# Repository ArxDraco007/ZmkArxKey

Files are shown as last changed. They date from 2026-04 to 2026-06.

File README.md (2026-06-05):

# ArxKey - A Custom Split Keyboard

## Building a custom wireless split mechanical keyboard from scratch.

## Why did I make this project?
  There are a lot of ill effects of using a non-ergonomic keyboard. Some basic effects happen, such as ulnar deviation (bending wrists outward), forearm pronation (palms facing down), and unnatural extension. It might also get very serious if you have Carpal Tunnel Syndrome (CTS): The median nerve in the wrist is compressed, often due to swollen tendons. It leads to numbness, tingling, and weakened grip strength. As the times change, you will require a keyboard as it becomes an integral part of your everyday life. It is best to have an ergonomic (furniture or equipment that makes it comfortable and effective for people who use it) keyboard, to make sure you enjoy your work.
You can also type very fast. It is also a very fun project to make, and it is also very cool to have your own custom keyboard (split one too).
### PICTURES!!!
The easy part -

1775320786451-4x2p1t

The not-so-easy part - 

1775912615627-d0wt4m

fusio' - 
left

## Assembly instructions - 
1. Heat-press the brass inserts into the case and glue the magnets into place.
2. Screw the stabilizers into the PCB and mount the sliding switch to the case.
3. Solder the diodes, Hall sensors, and header pins to the Seeeduino and PCB.
4. Connect the battery wires to the BAT pins and the sliding power switch.
5. Tuck the battery into its cavity and screw the PCB into the case.
6. Click switches into the plate, screw the plate to the case, and add keycaps.
7. Flash your ZMK firmware to the Seeeduino.
8. Repeat for the second half, pair them, and test your work.
   
## How to use it?
1. Power on both halves, the keyboard will show as ArxSplit in the PC/Phone's Bluetooth settings.
2. The right and left layers are in the general QWERTY layout.
3. Plug the USB-C port into your PC or a charger. The XIAO powers on immediately and also charges the LiPo battery connected to the BAT/VBAT pads.
4. Flashing Firmware - Push the ZMK Files/ directory to a GitHub repo.
5. It will build two .uf2 files, my_keyboard_left and my_keyboard_right.
6. Double-tap the Reset button on the XIAO — it enters bootloader mode and mounts as a USB drive called XIAO-SENSE or NRF52BOOT. Drag and drop the .uf2 file onto that drive. It flashes automatically and reboots.

## Zine!

zine_page-0001

| Name | Purpose | Quantity | Total Cost (USD) | Link | Distributor |
| :--- | :--- | :---: | :---: | :--- | :--- |
| **Hotswap Socket** | Fittings for the Cherry MX | 50 | 6.00 | [https://stackskb.com/store/gateron-hotswap-sockets/](https://stackskb.com/store/gateron-hotswap-sockets/) | Stackskb |
| **Seeed XIAO nRF52840** | Must be the nRF52840 version for Bluetooth | 2 | 32.00 | [https://makerbazar.in/products/seeed-studio-xiao-esp32s3-2-4ghz-wifi-ble-5-0](https://www.mouser.in/ProductDetail/Seeed-Studio/102010448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) | MakerBazar  |
| **LiPo Battery (3.7V)** | Battery for powering wireless. | 2 | 6.00 | [https://www.electropi.in/3.7v-300mah-lipo-battery-model-401230-india](https://www.electropi.in/3.7v-300mah-lipo-battery-model-401230-india) | Electropi |
| **Diodes (1N4148W)** | Diodes for core functionality. | 100 | 1.50 | [https://robu.in/product/1n4148w-slkor-75v-1v-4ns-150ma-sod-123-switching-diodes-rohs](https://robu.in/product/1n4148w-slkor-75v-1v-4ns-150ma-sod-123-switching-diodes-rohs) | Robu |
| **Cherry MX Switches** | Cherry MX switches are the industry standard for mechanical keyboards | 45 | 18.75 | [https://meckeys.com/shop/accessories/keyboard-accessories/key-switches/cherry-mx-rgb-switch/](https://meckeys.com/shop/accessories/keyboard-accessories/key-switches/cherry-mx-rgb-switch/) | Meckeys |
| **Resistors** | resistors for core functionality | 1 | 2.00 | [https://robu.in/product/1k-ohm-1-4w-0805-surface-mount-chip-resistor-pack-of-10](https://robu.in/product/1k-ohm-1-4w-0805-surface-mount-chip-resistor-pack-of-10) | Robu |
| **Custom PCB (JLCPCB)** | $2 for boards + ~$8 global shipping | 1 | 10.00 | [https://jlcpcb.com/](https://jlcpcb.com/) | JLCPCB | 
| **TOTAL** | | | **76.25** | | |

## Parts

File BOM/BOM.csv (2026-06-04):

Name | Purpose | Quantity | Total Cost (USD) | Link | Distributor
Hotswap Socket | Fittings for the Cherry MX | 50 | 6.00 | https://stackskb.com/store/gateron-hotswap-sockets/ | Stackskb
LiPo Battery (3.7V) | Look for "301230" or "401230" sizes (100-150mAh). | 2 | 6.00 | https://www.electropi.in/3.7v-300mah-lipo-battery-model-401230-india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 | Electropi
Diodes (1N4148W) | SOD-123 size (as per your KiCad layout). | 100 | 1.50 | https://robu.in/product/1n4148w-slkor-75v-1v-4ns-150ma-sod-123-switching-diodes-rohs | Robu
Seeed XIAO nRF52840 | Must be the nRF52840 version for Bluetooth. | 2 | 32.00 | https://makerbazar.in/products/seeed-studio-xiao-esp32s3-2-4ghz-wifi-ble-5-0?variant=48251063075056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 | MakerBazar
Resistors | 0805 resistors. | 1 | 2.00 | https://robu.in/product/1k-ohm-1-4w-0805-surface-mount-chip-resistor-pack-of-10 | Robu
Custom PCB (JLCPCB) | $2 for the boards + ~$8 for global shipping. | 1 | 10.00 | https://jlcpcb.com/ | JLCPCB
Cherry MX Switches | The keys. | 45 | 18.75 | https://meckeys.com/shop/accessories/keyboard-accessories/key-switches/cherry-mx-rgb-switch/ | mckeys
Total Cost |  |  | $76.25

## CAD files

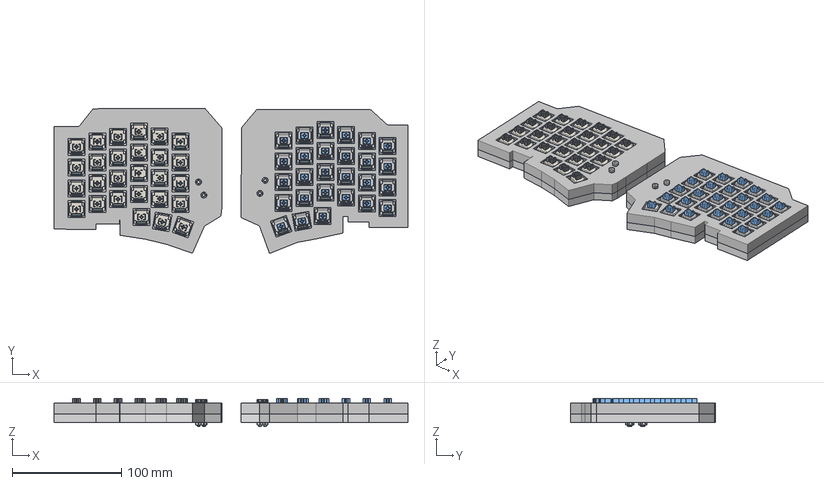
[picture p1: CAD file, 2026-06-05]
CAD/assembly.step
324.5 x 132.9 x 25.9 mm
Button x 27
Button_1 x 27
Pins x 27
D_SOD-123 x 27
91290A124_Black-Oxide Alloy Steel Socket Head Screw x 4
97700A110_Zinc Yellow-Chromate Plated Steel Hex Nut x 12

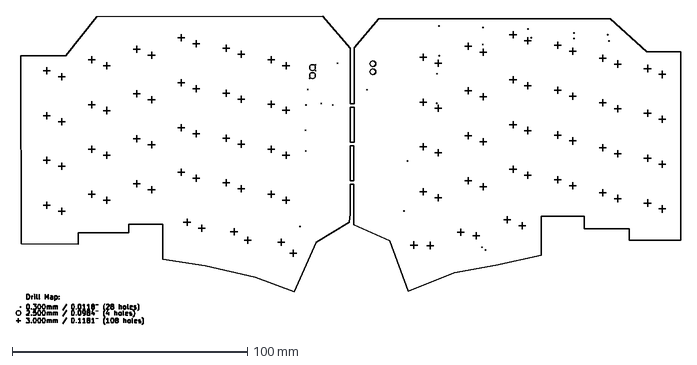
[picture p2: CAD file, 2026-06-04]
Gerber Files/Drill Files/ArxKey-PTH-drl_map.dxf
282.5 x 130.9 mm

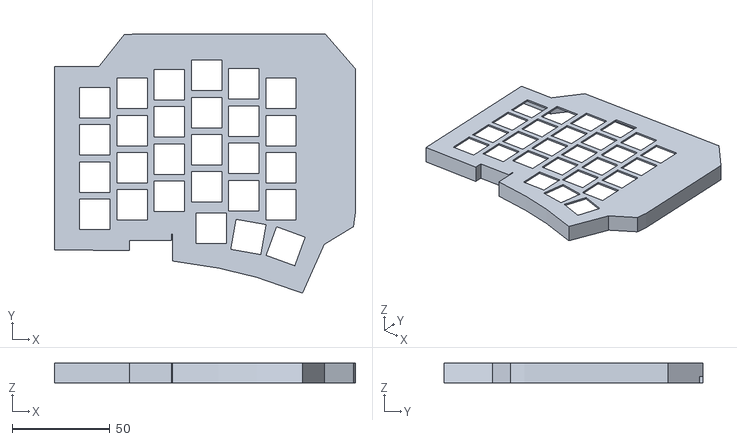
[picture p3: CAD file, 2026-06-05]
CAD/topleft.stl
154.0 x 132.7 x 10.00

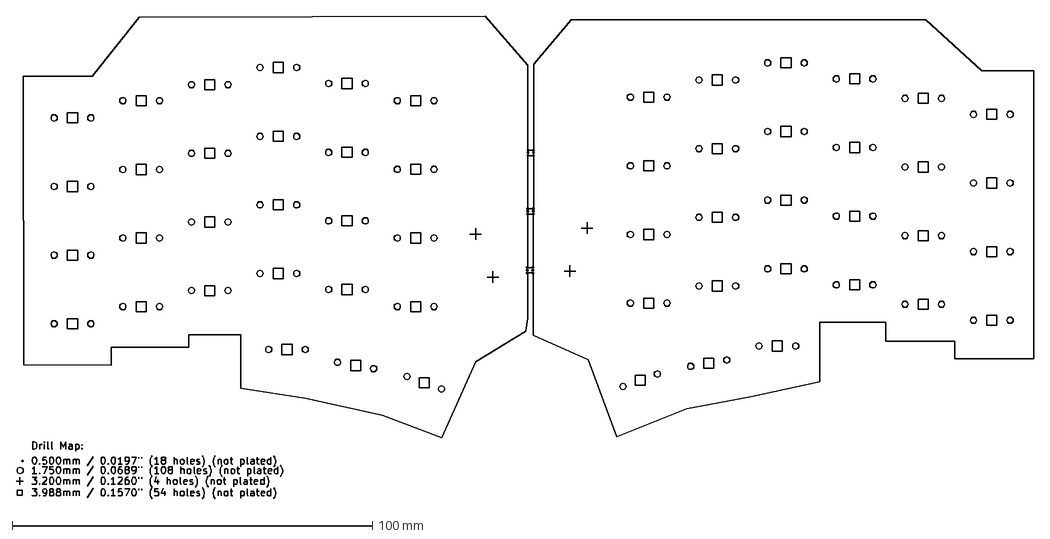
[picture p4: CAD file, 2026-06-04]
Gerber Files/Drill Files/ArxKey-NPTH-drl_map.dxf
282.5 x 133.9 mm

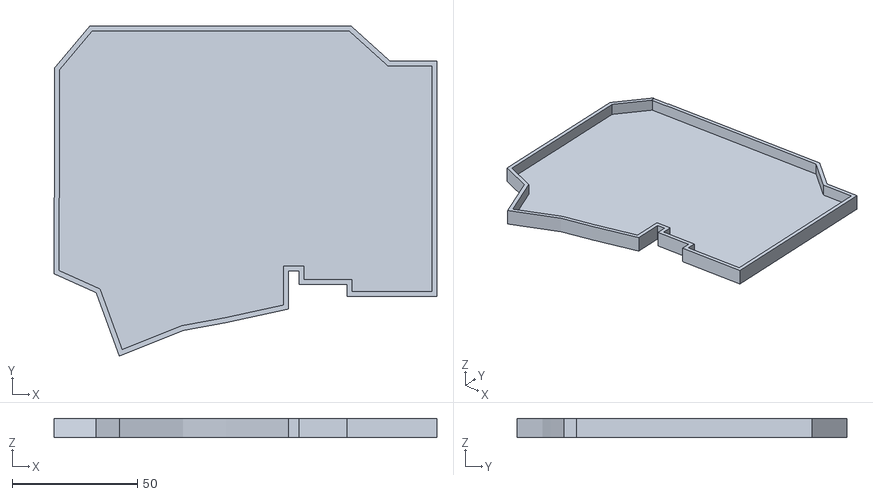
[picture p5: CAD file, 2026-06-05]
CAD/bottomright.stl
153.0 x 131.9 x 7.69

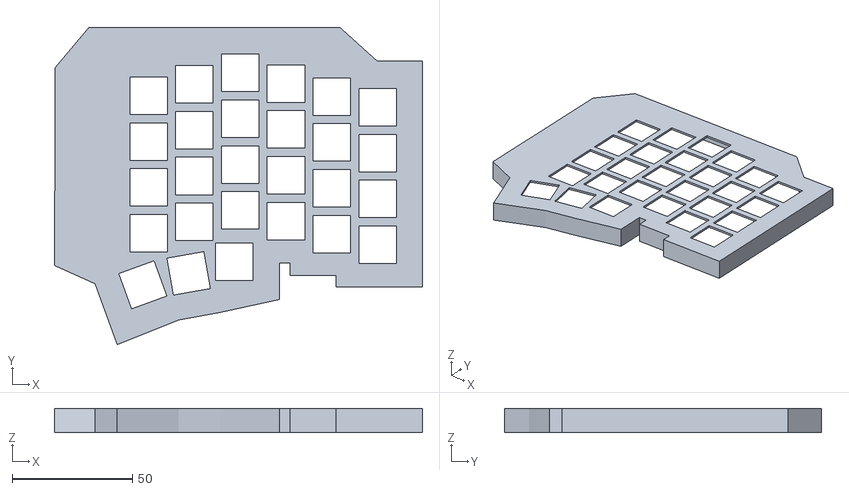
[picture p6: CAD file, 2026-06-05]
CAD/topright.stl
153.0 x 131.9 x 10.00

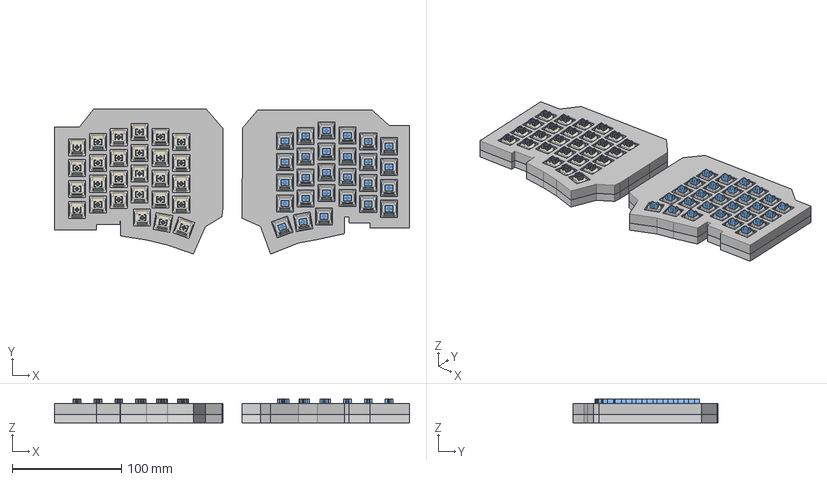
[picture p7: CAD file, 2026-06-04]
CAD/split_keyboard.step
324.5 x 132.9 x 21.9 mm

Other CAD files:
CAD/bottomleft.stl
CAD/assembly.f3z

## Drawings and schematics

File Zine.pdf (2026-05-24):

# ARXKey

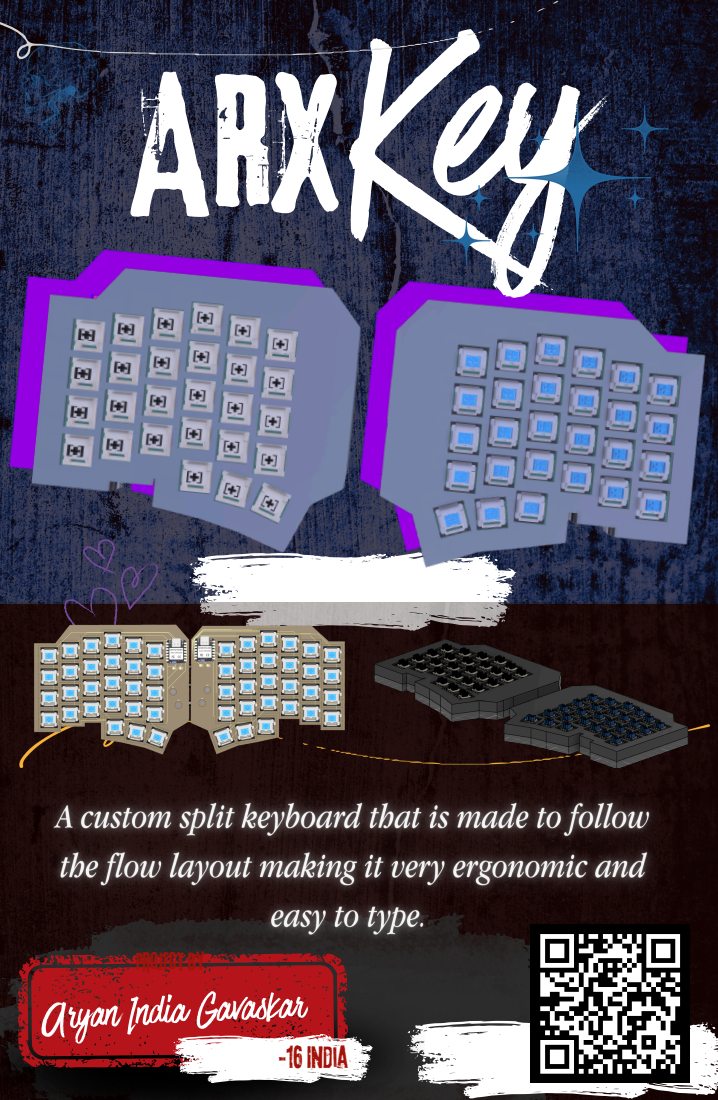
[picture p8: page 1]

A custom split keyboard that is made to follow
the flow layout making it very ergonomic and

easy to type.

Projectby

Aryan India Gavaskar

-16 India

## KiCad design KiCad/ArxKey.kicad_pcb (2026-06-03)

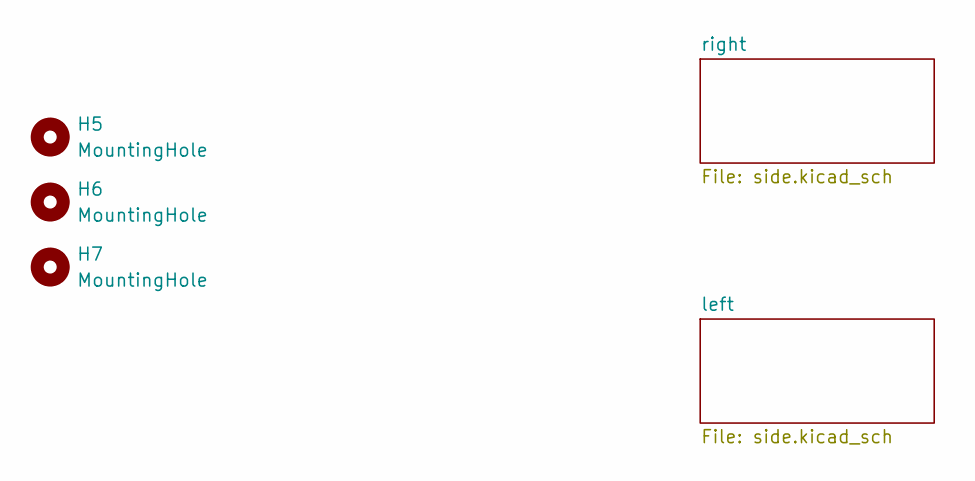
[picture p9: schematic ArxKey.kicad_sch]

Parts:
H5, H6, H7: MountingHole; mouse-bite-2mm-slot

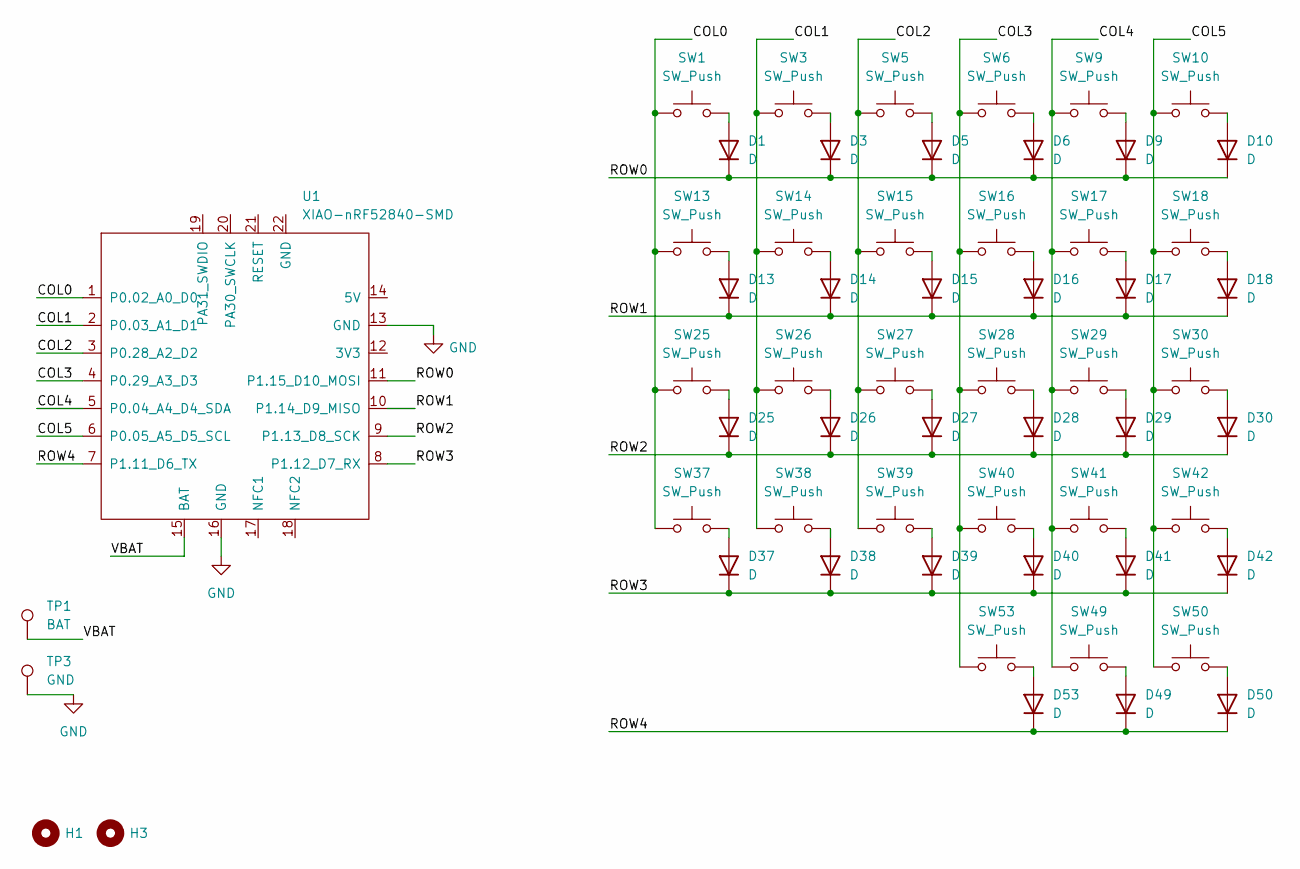
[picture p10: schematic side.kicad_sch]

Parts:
D1, D3, D5, D6, D9, D10, D13, D14, D15, D16, D17, D18, D25, D26, D27, D28, D29, D30, D37, D38, D39, D40, D41, D42, D49, D50, D53: D; D_SOD-123
H1, H3: MountingHole; MountingHole_3.2mm_M3
SW1, SW3, SW5, SW6, SW9, SW10, SW13, SW14, SW15, SW16, SW17, SW18, SW25, SW26, SW27, SW28, SW29, SW30, SW37, SW38, SW39, SW40, SW41, SW42, SW49, SW50, SW53: SW_Push; SW_MX_HS_KS-2P02B01-01_1u
TP1: BAT; TestPoint_Pad_D2.0mm
TP3: GND; TestPoint_Pad_D2.0mm
U1: XIAO-nRF52840-SMD; modified-XIAO-nRF52840-SMD

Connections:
/left/COL0: SW1.1, SW13.1, SW25.1, SW37.1, U1.1 (P0.02_A0_D0)
/left/COL1: SW3.1, SW14.1, SW26.1, SW38.1, U1.2 (P0.03_A1_D1)
/left/COL2: SW5.1, SW15.1, SW27.1, SW39.1, U1.3 (P0.28_A2_D2)
/left/COL3: SW6.1, SW16.1, SW28.1, SW40.1, SW53.1, U1.4 (P0.29_A3_D3)
/left/COL4: SW9.1, SW17.1, SW29.1, SW41.1, SW49.1, U1.5 (P0.04_A4_D4_SDA)
/left/COL5: SW10.1, SW18.1, SW30.1, SW42.1, SW50.1, U1.6 (P0.05_A5_D5_SCL)
/left/ROW0: D1.1 (K), D3.1 (K), D5.1 (K), D6.1 (K), D9.1 (K), D10.1 (K), U1.11 (P1.15_D10_MOSI)
/left/ROW1: D13.1 (K), D14.1 (K), D15.1 (K), D16.1 (K), D17.1 (K), D18.1 (K), U1.10 (P1.14_D9_MISO)
/left/ROW2: D25.1 (K), D26.1 (K), D27.1 (K), D28.1 (K), D29.1 (K), D30.1 (K), U1.9 (P1.13_D8_SCK)
/left/ROW3: D37.1 (K), D38.1 (K), D39.1 (K), D40.1 (K), D41.1 (K), D42.1 (K), U1.8 (P1.12_D7_RX)
/left/ROW4: D49.1 (K), D50.1 (K), D53.1 (K), U1.7 (P1.11_D6_TX)
/left/VBAT: TP1.1 (1_1), U1.15 (BAT)
GND: TP3.1 (1_1), U1.13 (GND), U1.16 (GND); also elsewhere on the board
unnamed: D1.2 (A), SW1.2
unnamed: D3.2 (A), SW3.2
unnamed: D5.2 (A), SW5.2
unnamed: D6.2 (A), SW6.2
unnamed: D9.2 (A), SW9.2
unnamed: D10.2 (A), SW10.2
unnamed: D13.2 (A), SW13.2
unnamed: D14.2 (A), SW14.2
unnamed: D15.2 (A), SW15.2
unnamed: D16.2 (A), SW16.2
unnamed: D17.2 (A), SW17.2
unnamed: D18.2 (A), SW18.2
unnamed: D25.2 (A), SW25.2
unnamed: D26.2 (A), SW26.2
unnamed: D27.2 (A), SW27.2
unnamed: D28.2 (A), SW28.2
unnamed: D29.2 (A), SW29.2
unnamed: D30.2 (A), SW30.2
unnamed: D37.2 (A), SW37.2
unnamed: D38.2 (A), SW38.2
unnamed: D39.2 (A), SW39.2
unnamed: D40.2 (A), SW40.2
unnamed: D41.2 (A), SW41.2
unnamed: D42.2 (A), SW42.2
unnamed: D49.2 (A), SW49.2
unnamed: D50.2 (A), SW50.2
unnamed: D53.2 (A), SW53.2

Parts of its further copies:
D2, D4, D7, D8, D11, D12, D19, D20, D21, D22, D23, D24, D31, D32, D33, D34, D35, D36, D43, D44, D45, D46, D47, D48, D51, D52, D54: D; D_SOD-123
H2, H4: MountingHole; MountingHole_3.2mm_M3
SW2, SW4, SW7, SW8, SW11, SW12, SW19, SW20, SW21, SW22, SW23, SW24, SW31, SW32, SW33, SW34, SW35, SW36, SW43, SW44, SW45, SW46, SW47, SW48, SW51, SW52, SW54: SW_Push; SW_MX_HS_KS-2P02B01-01_1u
TP2: BAT; TestPoint_Pad_D2.0mm
TP4: GND; TestPoint_Pad_D2.0mm
U2: XIAO-nRF52840-SMD; modified-XIAO-nRF52840-SMD

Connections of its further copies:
/right/COL0: SW2.1, SW19.1, SW31.1, SW43.1, U2.1 (P0.02_A0_D0)
/right/COL1: SW4.1, SW20.1, SW32.1, SW44.1, U2.2 (P0.03_A1_D1)
/right/COL2: SW7.1, SW21.1, SW33.1, SW45.1, U2.3 (P0.28_A2_D2)
/right/COL3: SW8.1, SW22.1, SW34.1, SW46.1, SW54.1, U2.4 (P0.29_A3_D3)
/right/COL4: SW11.1, SW23.1, SW35.1, SW47.1, SW51.1, U2.5 (P0.04_A4_D4_SDA)
/right/COL5: SW12.1, SW24.1, SW36.1, SW48.1, SW52.1, U2.6 (P0.05_A5_D5_SCL)
/right/ROW0: D2.1 (K), D4.1 (K), D7.1 (K), D8.1 (K), D11.1 (K), D12.1 (K), U2.11 (P1.15_D10_MOSI)
/right/ROW1: D19.1 (K), D20.1 (K), D21.1 (K), D22.1 (K), D23.1 (K), D24.1 (K), U2.10 (P1.14_D9_MISO)
/right/ROW2: D31.1 (K), D32.1 (K), D33.1 (K), D34.1 (K), D35.1 (K), D36.1 (K), U2.9 (P1.13_D8_SCK)
/right/ROW3: D43.1 (K), D44.1 (K), D45.1 (K), D46.1 (K), D47.1 (K), D48.1 (K), U2.8 (P1.12_D7_RX)
/right/ROW4: D51.1 (K), D52.1 (K), D54.1 (K), U2.7 (P1.11_D6_TX)
/right/VBAT: TP2.1 (1_1), U2.15 (BAT)
GND: TP4.1 (1_1), U2.13 (GND), U2.16 (GND); also elsewhere on the board
unnamed: D2.2 (A), SW2.2
unnamed: D4.2 (A), SW4.2
unnamed: D7.2 (A), SW7.2
unnamed: D8.2 (A), SW8.2
unnamed: D11.2 (A), SW11.2
unnamed: D12.2 (A), SW12.2
unnamed: D19.2 (A), SW19.2
unnamed: D20.2 (A), SW20.2
unnamed: D21.2 (A), SW21.2
unnamed: D22.2 (A), SW22.2
unnamed: D23.2 (A), SW23.2
unnamed: D24.2 (A), SW24.2
unnamed: D31.2 (A), SW31.2
unnamed: D32.2 (A), SW32.2
unnamed: D33.2 (A), SW33.2
unnamed: D34.2 (A), SW34.2
unnamed: D35.2 (A), SW35.2
unnamed: D36.2 (A), SW36.2
unnamed: D43.2 (A), SW43.2
unnamed: D44.2 (A), SW44.2
unnamed: D45.2 (A), SW45.2
unnamed: D46.2 (A), SW46.2
unnamed: D47.2 (A), SW47.2
unnamed: D48.2 (A), SW48.2
unnamed: D51.2 (A), SW51.2
unnamed: D52.2 (A), SW52.2
unnamed: D54.2 (A), SW54.2

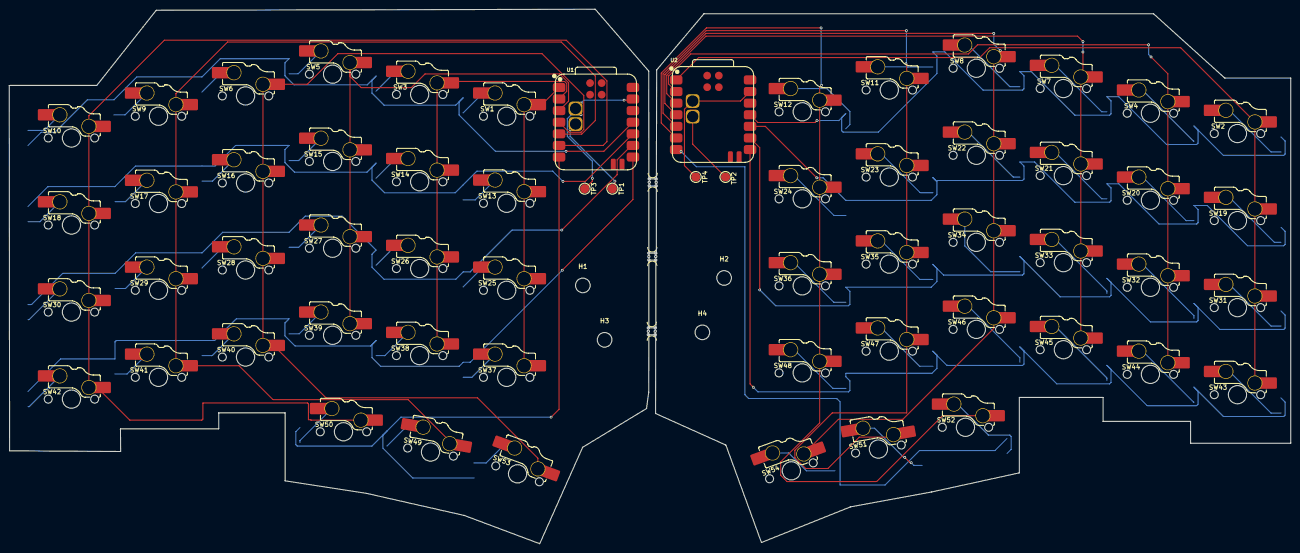
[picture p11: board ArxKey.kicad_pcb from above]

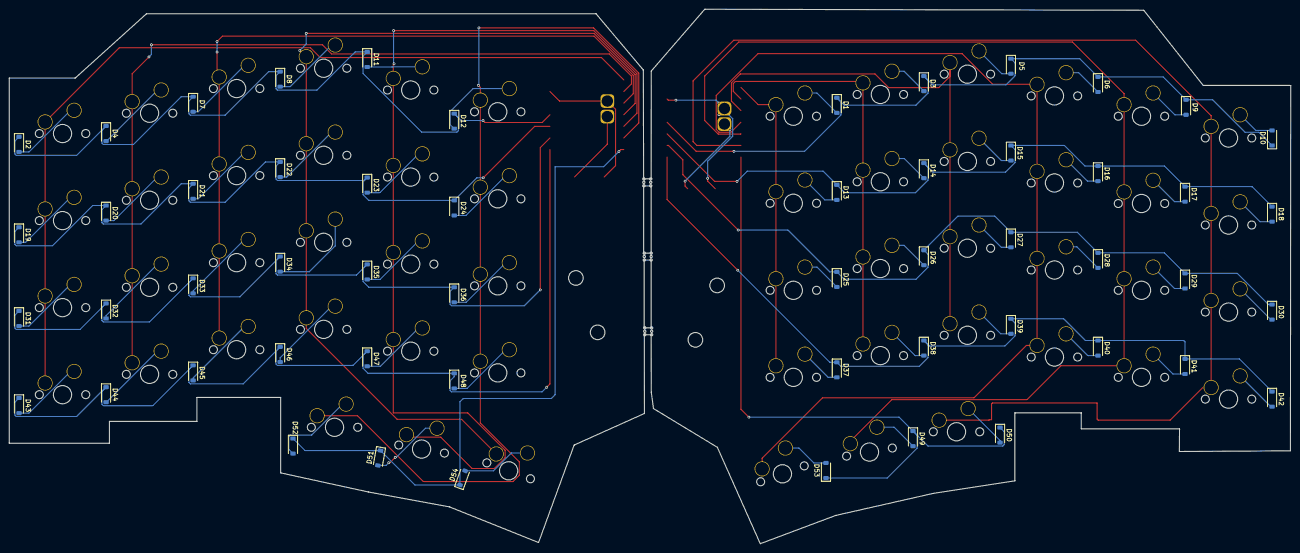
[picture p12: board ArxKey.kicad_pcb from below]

Board: 2 copper layers, 280.5 x 117.0 mm, 121 parts (54 on the bottom side), 79 nets.

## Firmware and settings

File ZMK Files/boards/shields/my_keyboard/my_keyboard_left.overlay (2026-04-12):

#include "my_keyboard.dtsi"

&kscan0 {
    col-gpios
        = <&xiao_d 0 GPIO_ACTIVE_HIGH> // COL0
        , <&xiao_d 1 GPIO_ACTIVE_HIGH> // COL1
        , <&xiao_d 2 GPIO_ACTIVE_HIGH> // COL2
        , <&xiao_d 3 GPIO_ACTIVE_HIGH> // COL3
        , <&xiao_d 4 GPIO_ACTIVE_HIGH> // COL4
        , <&xiao_d 5 GPIO_ACTIVE_HIGH> // COL5
        ;

    row-gpios
        = <&xiao_d 10 (GPIO_ACTIVE_HIGH | GPIO_PULL_DOWN)> // ROW0
        , <&xiao_d 9  (GPIO_ACTIVE_HIGH | GPIO_PULL_DOWN)> // ROW1
        , <&xiao_d 8  (GPIO_ACTIVE_HIGH | GPIO_PULL_DOWN)> // ROW2
        , <&xiao_d 7  (GPIO_ACTIVE_HIGH | GPIO_PULL_DOWN)> // ROW3
        , <&xiao_d 6  (GPIO_ACTIVE_HIGH | GPIO_PULL_DOWN)> // ROW4
        ;
};

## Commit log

2026-04-12 Kicad Files!
    Adding PCB and schematics
    [ArxKey.kicad_pcb, ArxKey.kicad_sch, side.kicad_sch]
2026-04-12 Add KiCad footprints, 3D models, and symbols
    Add multiple KiCad library items for PCB design: 3D models (D_SOD-123, MountingHole_2.2mm_M2, MouseBite-Part_2.0x2.0mm... Trace), footprints (mouse-bite-2mm-slot, modified XIAO-nRF52840-SMD, SW_MX_HE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
2026-04-12 Create ArxKey-bom.csv
    BOM file
    [ArxKey-bom.csv]
2026-04-12 Create README for custom split keyboard project
    Added a README file detailing the project for a custom wireless split mechanical keyboard, including a bill of materials and images.
2026-04-12 Update README with assembly instructions
    Added assembly instructions for building the keyboard.
2026-05-02 PCB Updates
    [ArxKey.kicad_pcb, ArxKey.kicad_sch, side.kicad_sch]
2026-05-04 Changes in README and CAD updates.
    [BOM.csv, bottomleft.3mf, topleft.3mf]
2026-05-05 stp files and 3mf files
    [bottomright.3mf, topright.3mf]
2026-05-05 CAD Design added
    [split_keyboard.step]
2026-05-24 zine and pcbv
    [ArxKey.kicad_pcb]
2026-05-24 Update README with new images and assembly steps
    Added additional images and assembly instructions to the README.
2026-06-04 gerber and drill
    [ArxKey-NPTH-drl_map.dxf, ArxKey-PTH-drl_map.dxf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]
2026-06-04 Add 1.5V LED Bulbs to components list
2026-06-05 assembly change
    [assembly.f3z]
2026-06-05 step file
    [assembly.step]
